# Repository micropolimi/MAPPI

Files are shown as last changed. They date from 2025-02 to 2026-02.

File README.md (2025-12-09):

# MAPPI - Macroscopic Plant Projection Imaging

License

🚀 **Open Software & Hardware for Plant Imaging**

---

## 🌱 Overview
MAPPI (MAcroscopic Plant Projection Imaging) is an open-source project dedicated to advanced imaging of growing plants. It provides tools for:
✅ Software-controlled optical imaging using cameras and LEDs.
✅ Automated data analysis with region-of-interest (ROI) registration.
✅ Hardware integration for multiview plant growth monitoring.

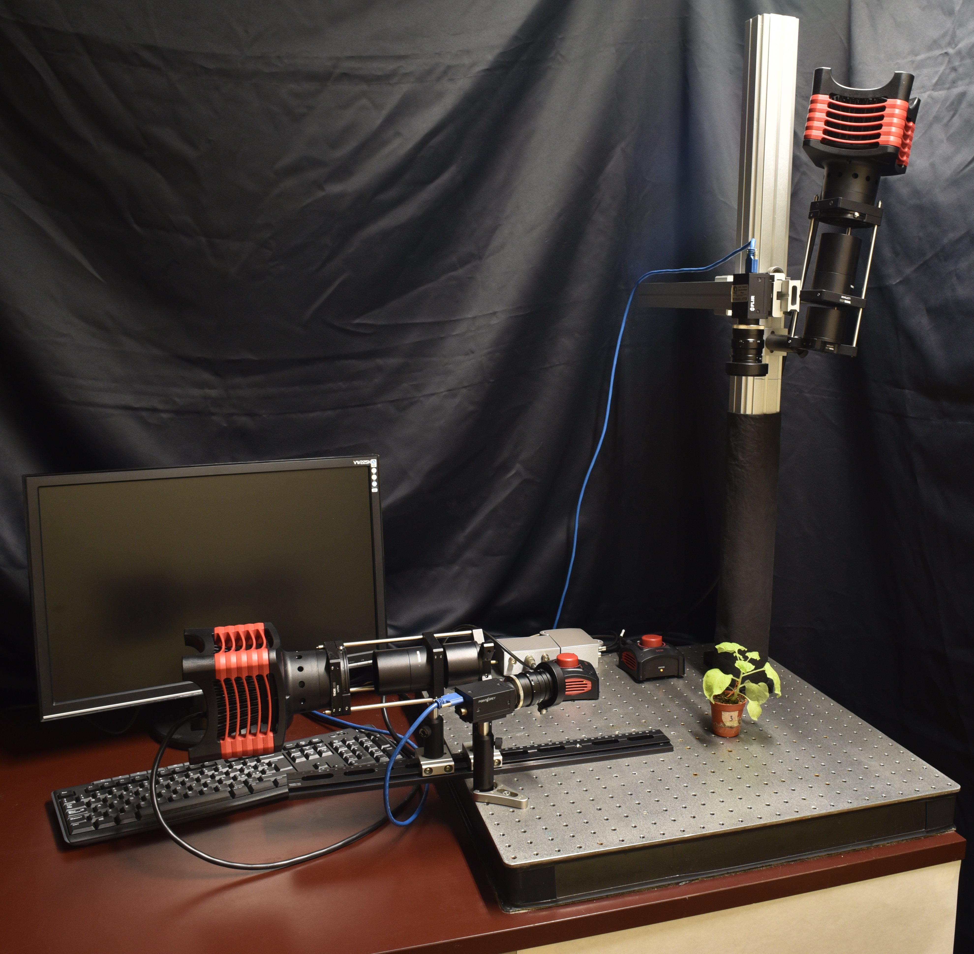
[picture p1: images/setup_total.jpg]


---

## 🖥️ Software Installation
The control software for MAPPI is based on [Scope Foundry]. To set up the python environment and install the software:
1. Follow the [Scope Foundry installation] guidelines.
2. Download or clone the [MAPPI code], which runs cameras, LEDs, and controls triggers with a dedicated [App].

---

## ⚙️ Software Usage
By running the *plant_app* script, a new window appears on the screen, allowing control of the MAPPI system. All acquisition parameters can be configured through the *PlantTimeLapseDualMeasure* widget, located above the canvas. A detailed description of the options offered by the *PlantTimeLapseDualMeasure* is provided below.

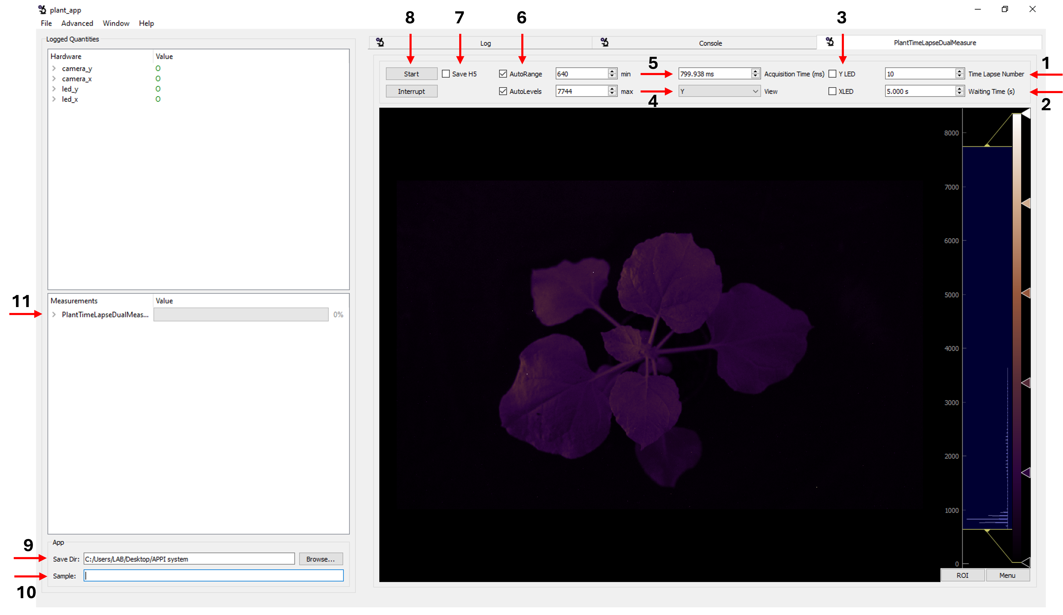
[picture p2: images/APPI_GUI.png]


1) **Time Lapse Number**: Number of time points to be acquired.
2) **Waiting Time**: Time interval between consecutive time points.
3) **X - Y LED**: When not measuring, ticking the checkbox toggles the selected LED on or off. Facilitates accurate positioning of the sample prior to measurement. 
4) **View**: Enables switching from one view to another.
5) **Acquisition Time**: Exposure time. Use 4) to select the appropriate channel and set the exposure time. Exposure time may differ between channels X and Y.
6) **AutoRange** and **AutoLevels**: When unchecked, these boxes allow the user to manually define the displayed portion of the Field of View and and set the grayscale level limits.
7) **Save H5**: When this checkbox is checked, pressing the Start button will save a new acquisition. 
8) **Start** and **Interrupt**: These two buttons start and stop the measurment respectively.
9) **Save Dr**: Directory where data will be saved.
10) **Sample**: Name of the file to be saved.
11) **State bar**: Displays the percentage of completed acquisitions.

---

## 📊 Data Analysis
For analyzing MAPPI datasets of growing plants, we recommend using the [napari ROI Registration plugin]. This plugin is specifically designed for time-lapse registration of regions-of-interest.

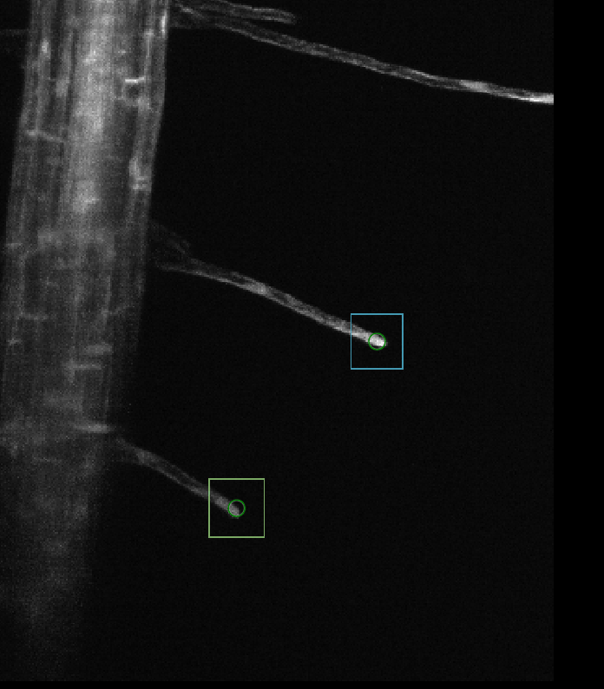
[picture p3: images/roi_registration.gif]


🔹 _Provides precise region tracking over time._   
🔹 _Easy-to-use with napari interface._

---

## 🛠️ Hardware Components
A list of all the components necessary to reproduce the MAPPI platform is available at the following [link].

---

## 🏗️ Hardware Installation
The MAPPI setup can be efficiently replicated by following the detailed step-by-step guide available [here].

---

## 🔬 3D-printed imaging chambers
Use MAPPI in combination with custom-made 3D-printed rhizoboxes to perform root imaging under near-physiological conditions. 

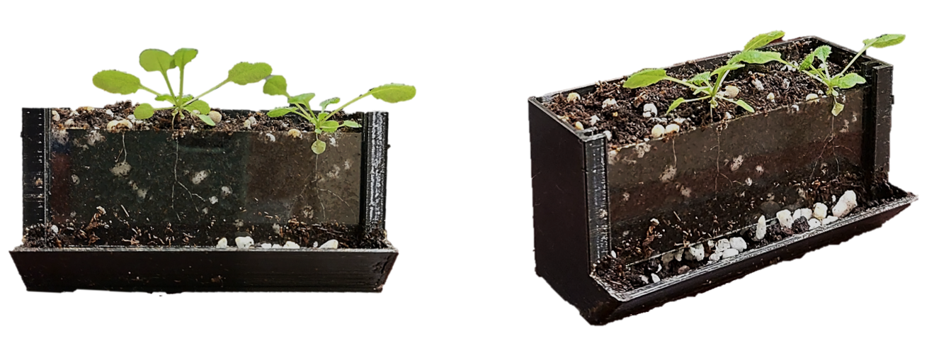
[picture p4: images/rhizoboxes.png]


We provide detailed [instructions] to reproduce the rhizoboxes and all the equipment needed to perform reliable shoot-to-root and root-to-shoot experiments on macroscopic plants. All the necessary STL files for 3D printing the equipment are available in the following [folder].

---

## 🍃 Case study
🚧 _Work in progress._ Stay tuned for updates!

---

## 🔓 License

Distributed under the terms of the [BSD-3] license,
the MAPPI code is free and open source software

---

## 📬 Contribute & Support
Have suggestions or issues? Feel free to [file an issue] or contribute to the project!

🔗 **Useful Links:**
- [Scope Foundry] - Imaging framework
- [Scope Foundry Installation] - Step-by-step setup guide
- [MAPPI Code] - Source files
- [napari ROI Registration Plugin] - Data analysis tool

[Scope Foundry]: https://scopefoundry.org/
[Scope Foundry installation]: https://scopefoundry.org/docs/1_getting-started/
[file an issue]: https://github.com/micropolimi/APPI/issues
[MAPPI code]: https://github.com/micropolimi/APPI/raw/main/src
[App]: https://github.com/micropolimi/APPI/raw/main/src/plant_app.py
[napari Roi Registration plugin]: https://www.napari-hub.org/plugins/napari-roi-registration
[BSD-3]: http://opensource.org/licenses/BSD-3-Clause
[here]: https://github.com/micropolimi/APPI/blob/main/docs/hardware.md
[link]: https://github.com/micropolimi/APPI/blob/main/docs/components.md
[folder]: https://github.com/micropolimi/APPI/tree/main/docs/STL_files
[instructions]: https://github.com/micropolimi/APPI/blob/main/docs/3D_printing.md

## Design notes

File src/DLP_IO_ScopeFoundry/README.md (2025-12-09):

# DLP_IO_ScopeFoundry
ScopeFoundry code for IO board DLP-IO8-G USB-BASED 8-CHANNEL DATA ACQUISITION MODULE

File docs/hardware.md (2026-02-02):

# Build your own MAPPI platform

This section presents a step-by-step guide to facilitate the replication of the MAPPI setup, using the components listed at the following [link].

## Horizontal arm



### Step 1: LED, lens and filter units.
#### LED unit
Begin by taking the LED (1) and mounting the [SM2L05] component onto it (2). Next, place the [LCP36] on top of the [SM2L05] and insert and fix three rods ([ER8-P4], 3). Position the rods to minimize the portion which extends beyond the cage on the LED side. Using three rods instead of four will facilitate the installation of the subsequent components. Finally, mount the iris ([LCP50D]) in such a way that it remains easily accessible once the entire setup is assembled (4).



#### Lens unit
Take the clamping platform ([XT66C4], 1) and mount the [post holder] on top of it (2). Then add the [post] (3), and finally mount the cage that will hold the lens ([LCP34/M], 4).



#### Filter unit
Take the clamping platform ([XT66C4], 1) and mount the [post holder] on top of it (2). Add the [post] (3), and then mount the cage that will be used to hold the short-pass filter ([LCP33/M], 4). Screw a [retaining ring] into the cage and insert the filter into the cage (5). A second retaining ring is not required to secure the filter, as the [SM1A2] adapter will serve this function during the assembly of the entire horizontal arm.



### Step 2: assemble the horizontal arm
Mount the horizontal rail ([XT66SD-500], 1) onto the breadboard. Pay close attention to positioning, ensuring that there is sufficient space on the breadboard to place the sample 45 cm away from the last lens once the entire setup is assembled. Fix the lens unit onto the rail (2). At this stage, the exact position of the lens unit along the rail is not critical. Once the entire illumination unit is complete, it can be precisely positioned along the rail thanks to the movable clamping platforms. Next, add the LED unit (3), followed by the filter unit (4). The LED, lens, and filter units are connected using rods. You can now screw the lens ([AC508-075-A-ML]) onto the lens unit (5). The distance between the iris mounted on the LED unit and the center of the lens must be approximetely 9 cm. As a result, the lens will create an enlarged image of the homogeneous illumination plane formed at the iris, located 45 cm away. The most effective way to adjust the distance between the iris and the lens is to temporarily remove the filter unit from the rail and observe how the illumination plane behaves at a distance of 45 cm from the lens, while adjusting the position of the LED unit relative to the lens unit. The optimal position is the one that maximizes the homogeneity of the illumination at 45 cm. Open and close the iris aperture to ensure that the homogeneity of the illumination plane does not depend on the iris aperture. Mount the [SM2L15] tube onto lens (6).



Once you are satisfied with the positioning of the LED relative to the lens, you can reattach the filter unit to the rail. The filter unit should be positioned at the focal plane of the lens, where the image of the LED source (four emitters) is formed (see image below). Identify this point along the optical path and fix the filter unit in place.

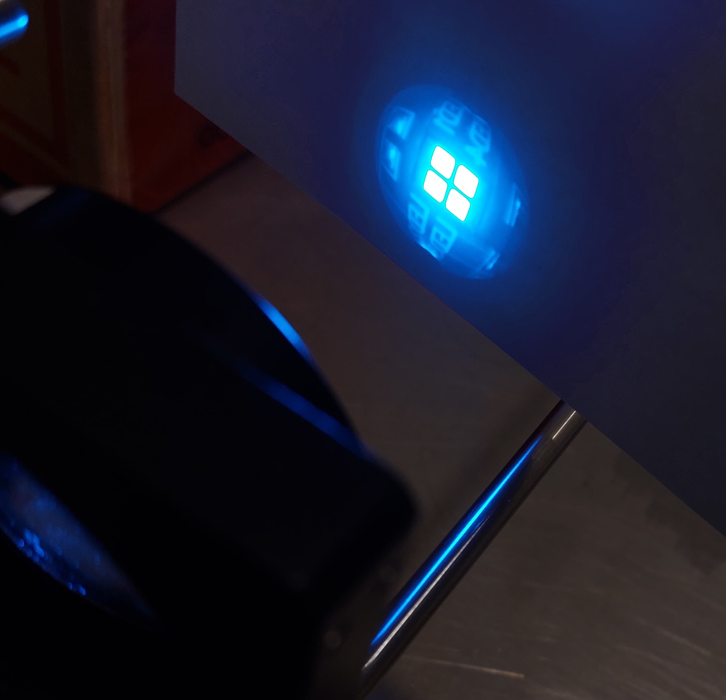
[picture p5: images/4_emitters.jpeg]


Add the [SM1A2] to the filter unit (7). This will secure the filter within its cage. Mount the [SM2L20] tube onto the SM1A2 (8). The illumination unit is now complete. You can adjust its position on the rail and place it in its final location.



Mount the post holder onto the base adapter ([BE1]), and secure them to the breadboard using a [clamping fork] (9). Insert the [post] (10) and screw the camera onto it (11). You can now connect the camera. Mount the objective onto the camera (12), add the 3D-printed support for the filter (13), and then screw in the [SM2L05] tube containing the mounted band-pass filter (14). The horizontal arm of the MAPPI setup is now complete. 



## Vertical arm



### Step 1: camera and illumination units
#### Camera unit
For the vertical arm, the camera must be mounted on a clamping platform ([XT66C4]). Even when using the shortest screw, it is not possible to secure the camera directly to the platform because the threaded hole on the camera is too shallow. To resolve this, two metal rings (available [here]) should be used to increase the effective thickness, as shown in panel 1. Align the rings with the hole on the camera (2), then attach the camera to the clamping platform (3). You're camera unit is ready. Any other strategy to increase the thickness and fix the camera to the platform can be used. 

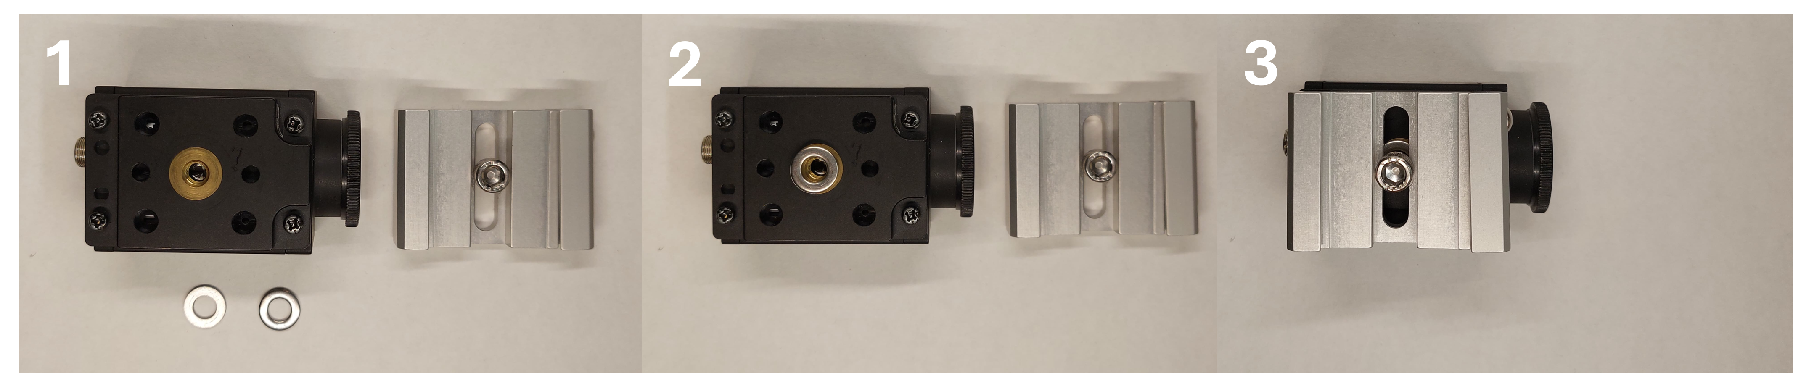
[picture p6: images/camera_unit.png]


#### Illumination unit
The same instructions used to build the horizontal illumination unit should be followed to assemble the vertical one. The only difference lies in how the lens unit is mounted onto the clamping platform. In this case, the lens unit is secured to the clamping platform using a clamping fork (see figure below). This configuration allows the vertical illumination unit to be slightly tilted rather than perfectly vertical. In this way, it is possible to illuminate the same area imaged by the camera while keeping the camera parallel to the sample plane.

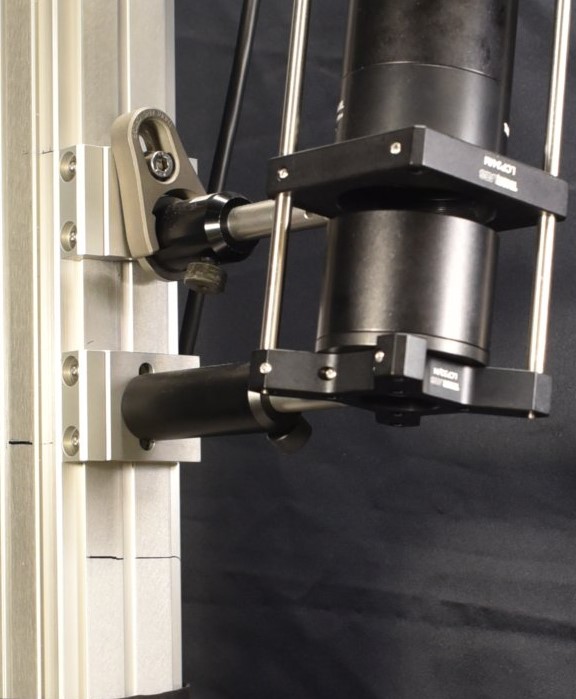
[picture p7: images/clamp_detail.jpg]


### Step 2: assemble the vertical arm
Mount the vertical shaft ([XT66-100]) using the vertical mounting plate ([XT66P1]), and cover the lower part of the shaft with a black cloth to avoid unwanted light reflections during measurements (1). Mount the illumination unit on one side of the shaft using the clamping platforms (2). Adjust the height of the illumination unit along the shaft according to the sample dimensions, maintaining a distance of 45 cm between the last lens and the sample.
Mount one of the two double dovetail clamps ([XT66C2]) on another side of the shaft (3), specifically on the side where the horizontal arm of the MAPPI platform is located. Attach the cross bracket ([XT66CB]) to the double dovetail clamp (4), then mount the second XT66C2 onto the cross bracket (5). Add the rail ([XT66DP-500]) that will hold the camera vertically above the sample (6). Mount the camera unit onto this rail near the LED (7). Finally, screw the objective (already fitted with the filter) onto the camera, and connect the camera (8). Your MAPPI platform is now complete.



[link]: https://github.com/micropolimi/MAPPI/blob/main/docs/components.md
[LCP36]: https://www.thorlabs.de/thorproduct.cfm?partnumber=LCP36
[ER8-P4]: https://www.thorlabs.com/thorproduct.cfm?partnumber=ER8-P4
[LCP50D]: https://www.thorlabs.com/thorproduct.cfm?partnumber=LCP50D
[XT66C4]: https://www.thorlabs.com/thorproduct.cfm?partnumber=XT66C4
[LCP34/M]: https://www.thorlabs.com/thorproduct.cfm?partnumber=LCP34/M
[LCP33/M]: https://www.thorlabs.com/thorproduct.cfm?partnumber=LCP33/M
[SM1A2]: https://www.thorlabs.com/thorproduct.cfm?partnumber=SM1A2
[XT66SD-500]: https://www.thorlabs.com/thorproduct.cfm?partnumber=XT66SD-500
[AC508-075-A-ML]: https://www.thorlabs.com/thorproduct.cfm?partnumber=AC508-075-A-ML
[SM2L15]: https://www.thorlabs.com/thorproduct.cfm?partnumber=SM2L15
[SM1A2]: https://www.thorlabs.com/thorproduct.cfm?partnumber=SM1A2
[SM2L20]: https://www.thorlabs.com/thorproduct.cfm?partnumber=SM2L20
[BE1]: https://www.thorlabs.com/thorproduct.cfm?partnumber=BE1/M#ad-image-0
[SM2L05]: https://www.thorlabs.com/thorproduct.cfm?partnumber=SM2L05
[XT66-100]: https://www.thorlabs.com/thorproduct.cfm?partnumber=XT66-100
[XT66P1]: https://www.thorlabs.com/thorproduct.cfm?partnumber=XT66P1
[XT66C2]: https://www.thorlabs.com/thorproduct.cfm?partnumber=XT66C2
[XT66CB]: https://www.thorlabs.com/thorproduct.cfm?partnumber=XT66CB
[XT66DP-500]: https://www.thorlabs.com/thorproduct.cfm?partnumber=XT66DP-500
[post]: https://www.thorlabs.com/thorproduct.cfm?partnumber=TR75/M
[post holder]: https://www.thorlabs.com/thorproduct.cfm?partnumber=PH75/M-P5#ad-image-0
[retaining ring]:https://www.thorlabs.com/thorproduct.cfm?partnumber=SM1RR
[clamping Fork]:https://www.thorlabs.com/thorproduct.cfm?partnumber=CF125C/M#ad-image-0
[here]:https://www.thorlabs.com/thorproduct.cfm?partnumber=HW-KIT2/M

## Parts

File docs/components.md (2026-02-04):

# List of components

| Component | Image | Provider | Description | Quantity | Unit | Price of a single item |
|---|---|---|---|---|---|---|
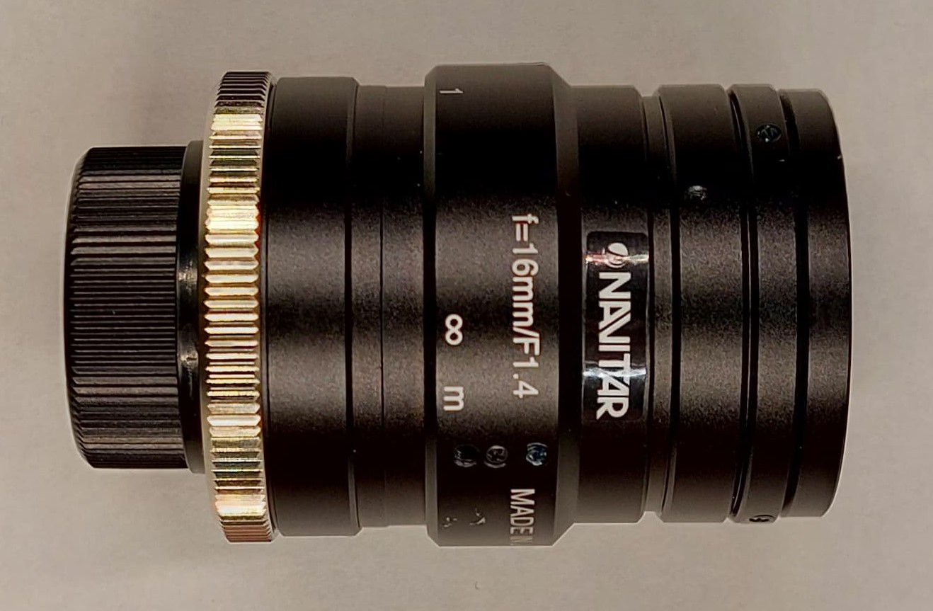
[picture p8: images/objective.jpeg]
|[MVL16M1]||Thorlabs|16 mm EFL, f/1.4, for 1" C-Mount Format Cameras, with Lock|2|Detection Unit|526,87 €|
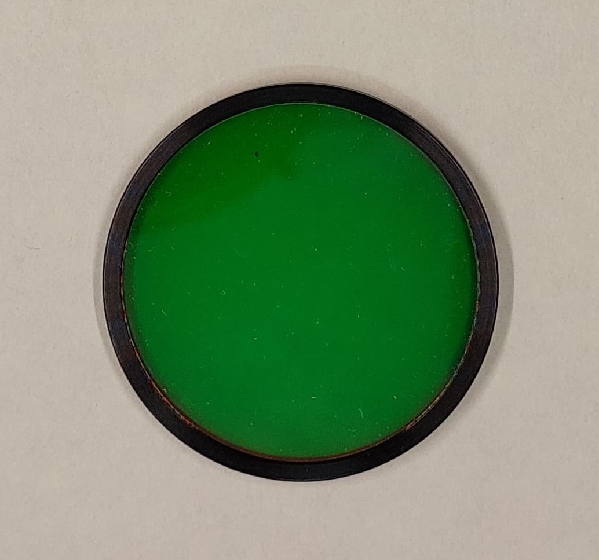
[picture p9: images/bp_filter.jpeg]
|[B-P Filter]||Edmund Optics|543nm CWL, 50mm Dia, 22nm Bandwidth, OD 6 Fluorescence Filter|2|Detection Unit|912,58 €|
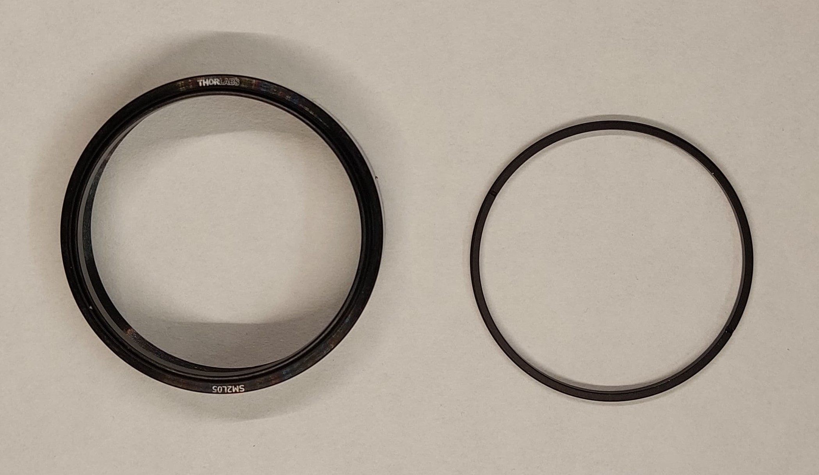
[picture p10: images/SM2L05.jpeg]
|[SM2L05]||Thorlabs|SM2L05 - SM2 Lens Tube, 0.5" Thread Depth, One Retaining Ring Included|4|Detection Unit/LED unit|27,64 €|
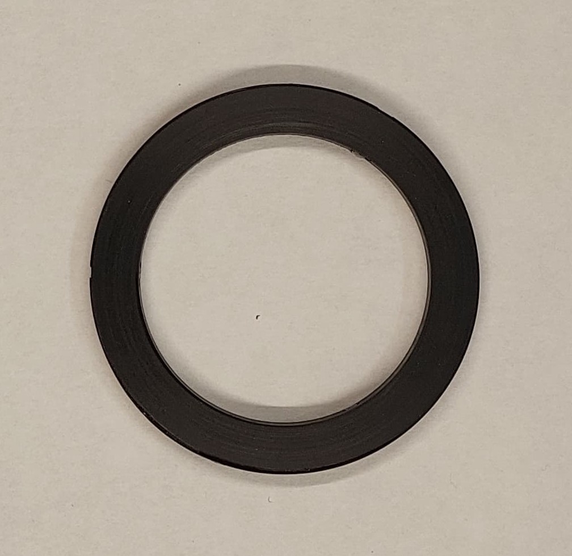
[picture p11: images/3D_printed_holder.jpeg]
|3D-printed filter holder||Custom made|3D-printed adapter for direct filter mounting on the objective|2|Detection Unit| - |
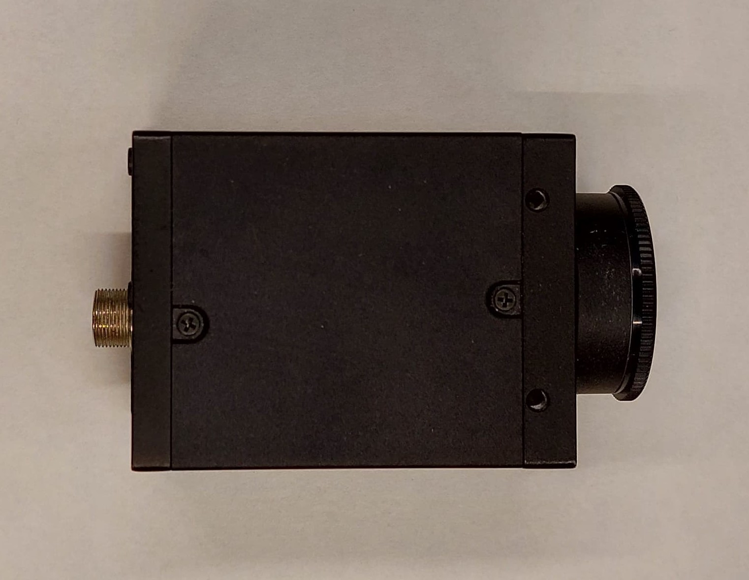
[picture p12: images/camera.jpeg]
|[camera]||Edmund optics|GS3-U3-23S6M-C 1/1.2" FLIR Grasshopper®3 High Performance USB 3.0 Monochrome Camera|2|Detection Unit|1.180 €|
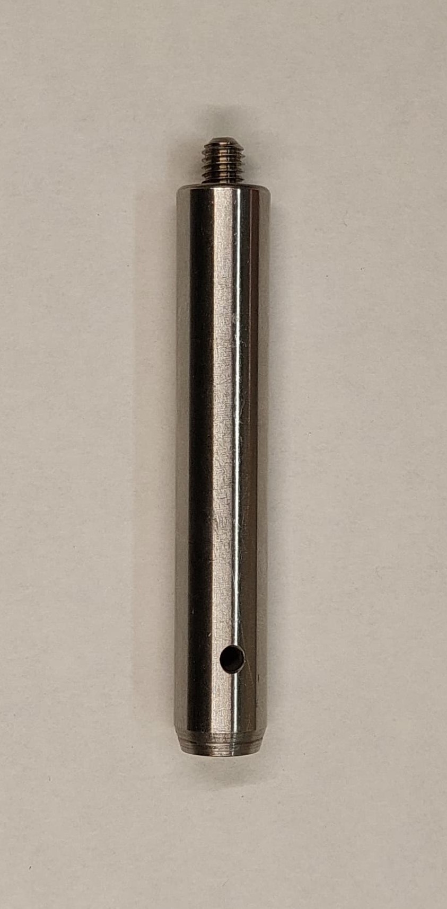
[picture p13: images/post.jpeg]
|[Post]||Thorlabs|TR75/M-P5 - Ø12.7 mm Optical Post, SS, M4 Setscrew, M6 Tap, L = 75 mm, 5 Pack|1|H/V arm|26,94 €|
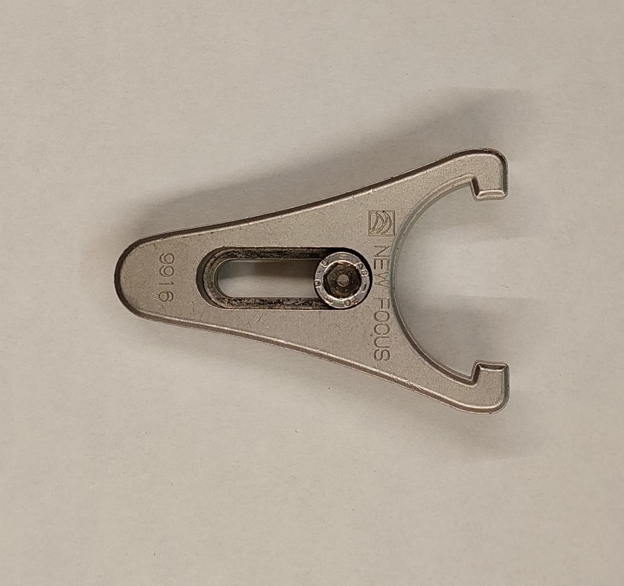
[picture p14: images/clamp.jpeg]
|[Clamping Fork]||Thorlabs|CF125C/M - Clamping Fork for Ø1.25" Pedestal Bases, 31.5 mm Counterbored Slot, M6 x 1.0 Captive Screw|2|H detection unit/V lens unit|12,48 €|
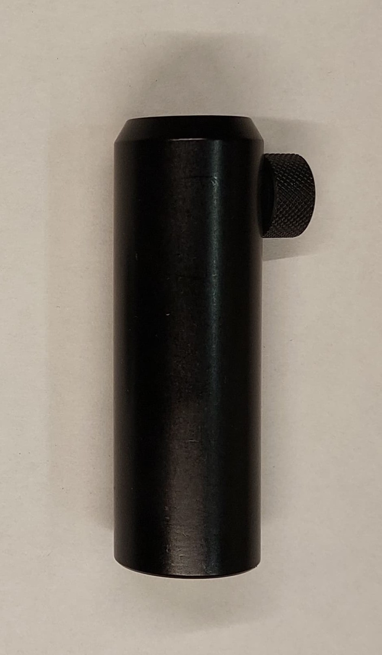
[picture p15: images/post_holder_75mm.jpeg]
|[Post Holder (75 mm)]||Thorlabs|PH75/M-P5 - Ø12.7 mm Post Holder, Spring-Loaded Hex-Locking Thumbscrew, L=75 mm, 5 Pack|1|H/V arm|44,58 €|
|[Base Adapter]||Thorlabs|BE1/M - Ø31.8 mm Studded Pedestal Base Adapter, M6 Threads|2|H detection unit/V lens unit|10,54 €|
|[SM2L15]||Thorlabs|SM2L15 - SM2 Lens Tube, 1.5" Thread Depth, One Retaining Ring Included|2|H/V arm|33,11 €|
|[SM2L20]||Thorlabs|SM2L20 - SM2 Lens Tube, 2" Thread Depth, One Retaining Ring Included|2|H/V arm|33,66 €|
|[SM1A2]||Thorlabs|SM1A2 - Adapter with External SM1 Threads and Internal SM2 Threads|2|H/V arm|27,62 €|
|[AC508-075-A-ML]||Thorlabs|f=75 mm, Ø2" Achromatic Doublet, SM2-Threaded Mount, ARC: 400-700 nm|2|H/V arm|176,77 €|
|[LCP33/M]||Thorlabs|30 mm to 60 mm Cage Plate Adapter, M4 Tap|2|Filter Unit|45,06 €|
|[FESH0500]||Thorlabs|Ø25.0 mm Shortpass Filter, Cut-Off Wavelength: 500 nm|2|Filter Unit|153,86 €|
|[XT66C4]||Thorlabs|Clamping Platform for 66 mm Rails, 1/4" Counterbored Slot, 40 mm Long|5|H/V arm|32,35 €|
|[LCP34/M]||Thorlabs|LCP34/M - 60 mm Cage Plate, SM2 Threads, 0.5" Thick, M4 Tap (Two SM2RR Retaining Rings Included)|2|Lens Unit|43,91 €|
|[LCP50D]||Thorlabs|60 mm Cage System Iris Diaphragm (Ø2.0 - Ø50.0 mm)|2|LED Unit|219,53 €|
|[SOLIS-470C]||Thorlabs|High-Power LED for Microscopy, 470 nm (Blue), 3.0 W (Min)|2|LED Unit|1.424,19 €|
|[DC20]||Thorlabs|High-Power Driver for Solis® LEDs, 10 A Max, 14.0 V Max|2|LED Unit|560,71 €|
|[ER8-P4]||Thorlabs|Cage Assembly Rod, 8" Long, Ø6 mm, 4 Pack|2|LED Unit|46,77 €|
|[LCP36]||Thorlabs|60 mm Cage Plate with Ø2.2" (Ø56.0 mm) Double Bore for SM2 Lens Tube Mounting|2|LED Unit|48,80 €|
|[XT66SD-500]||Thorlabs|66 mm Single Dovetail Rail with Mounting Counterbores, L = 500 mm|1|H arm|92,87 €|
|[XT66-1000]||Thorlabs|66 mm Construction Rail, L = 100 mm|1|V arm|171,42 €|
[XT66P1]||Thorlabs|Vertical Mounting Plate for 34 mm & 66 mm Optical Rails|1|V arm|41,02 €|
|[XT66C2]||Thorlabs|40 mm Long Double Dovetail Clamp for 66 mm Rails |2|V arm|24,91 €|
|[XT66DP-500]||Thorlabs|66 mm Double Dovetail Rail, L = 500 mm|1|V arm|52,00 €|
|[XT66CB]||Thorlabs|Cross Bracket for 66 mm Rails|1|V arm|24,03 €|
|[DLP-IO8-G]||Digikey|MODULE DATA-ACQUISITION 8-CH|2|H/V arm|26,23 €|
|[Breadboard]||Thorlabs|B6060L - Nexus Breadboard, 600 mm x 600 mm x 60 mm, Sealed M6 x 1.0 Mounting Holes|1|-|1116,05 €|
|[Table clamp]||Thorlabs|CL5 - Table Clamp, L-Shap|2|V arm|5,15 €|
|Double BNC cable||-|Double BNC cable|2|H/V arm|-|
|[Retaining ring]||Thorlabs|SM1RR - SM1 Retaining Ring for Ø1" Lens Tubes and Mounts |2|Filter unit|4,74 €|
|[Screw kit]||Thorlabs|HW-KIT2/M - M6 Cap Screw and Hardware Kit|1|-|135,76 €|

[MVL16M1]: https://www.thorlabs.com/thorproduct.cfm?partnumber=MVL16M1
[camera]: https://www.edmundoptics.com/p/gs3-u3-23s6m-c-112-grasshopper-usb-30-monochrome-camera/30859/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
[SM2L05]: https://www.thorlabs.com/thorproduct.cfm?partnumber=SM2L05
[Base Adapter]: https://www.thorlabs.com/thorproduct.cfm?partnumber=BE1/M#ad-image-0
[SM2L15]: https://www.thorlabs.com/thorproduct.cfm?partnumber=SM2L15
[SM2L20]: https://www.thorlabs.com/thorproduct.cfm?partnumber=SM2L20
[SM1A2]: https://www.thorlabs.com/thorproduct.cfm?partnumber=SM1A2
[AC508-075-A-ML]: https://www.thorlabs.com/thorproduct.cfm?partnumber=AC508-075-A-ML
[LCP33/M]: https://www.thorlabs.com/thorproduct.cfm?partnumber=LCP33/M
[FESH0500]: https://www.thorlabs.com/thorproduct.cfm?partnumber=FESH0500
[XT66C4]: https://www.thorlabs.com/thorproduct.cfm?partnumber=XT66C4
[LCP34/M]: https://www.thorlabs.com/thorproduct.cfm?partnumber=LCP34/M
[LCP50D]: https://www.thorlabs.com/thorproduct.cfm?partnumber=LCP50D
[SOLIS-470C]: https://www.thorlabs.com/thorproduct.cfm?partnumber=SOLIS-470C
[DC20]: https://www.thorlabs.com/thorproduct.cfm?partnumber=DC20
[ER8-P4]: https://www.thorlabs.com/thorproduct.cfm?partnumber=ER8-P4
[LCP36]: https://www.thorlabs.de/thorproduct.cfm?partnumber=LCP36
[XT66SD-500]: https://www.thorlabs.com/thorproduct.cfm?partnumber=XT66SD-500
[XT66P1]: https://www.thorlabs.com/thorproduct.cfm?partnumber=XT66P1
[XT66-1000]: https://www.thorlabs.com/item/XT66-1000
[XT66C2]: https://www.thorlabs.com/thorproduct.cfm?partnumber=XT66C2
[XT66DP-500]: https://www.thorlabs.com/thorproduct.cfm?partnumber=XT66DP-500
[XT66CB]: https://www.thorlabs.com/thorproduct.cfm?partnumber=XT66CB
[DLP-IO8-G]: https://www.digikey.it/it/products/detail/dlp-design-inc/DLP-IO8-G/1894342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
[Post Holder (75 mm)]: https://www.thorlabs.com/thorproduct.cfm?partnumber=PH75/M-P5#ad-image-0
[Post]: https://www.thorlabs.com/thorproduct.cfm?partnumber=TR75/M-P5
[B-P Filter]:https://www.edmundoptics.eu/p/543nm-cwl-50mm-dia-22nm-bandwidth-od-6-fluorescence-filter/21586/
[Clamping Fork]:https://www.thorlabs.com/thorproduct.cfm?partnumber=CF125C/M#ad-image-0
[Breadboard]:https://www.thorlabs.com/thorproduct.cfm?partnumber=B6060L
[Table clamp]:https://www.thorlabs.com/thorproduct.cfm?partnumber=CL5
[Retaining ring]:https://www.thorlabs.com/thorproduct.cfm?partnumber=SM1RR
[Screw kit]:https://www.thorlabs.com/thorproduct.cfm?partnumber=HW-KIT2/M

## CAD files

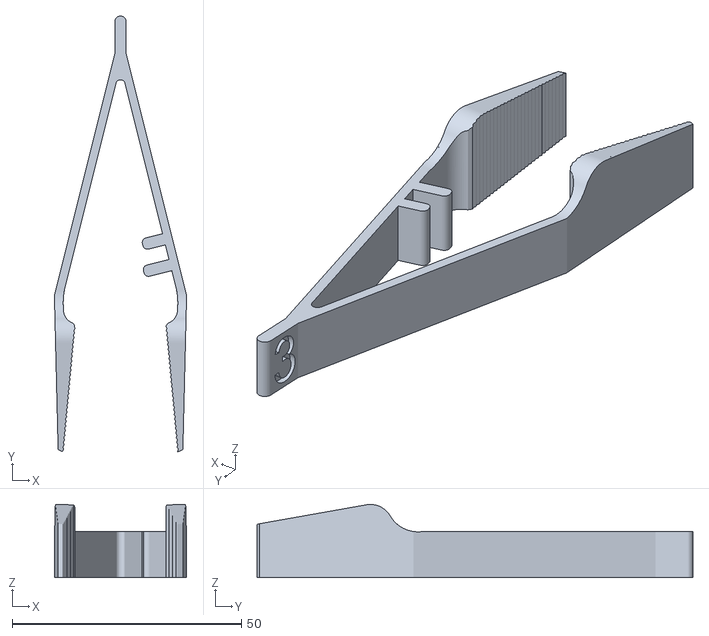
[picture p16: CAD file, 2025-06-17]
docs/STL_files/Wounding_tweezer_#3.stl
28.9 x 95.1 x 16.0

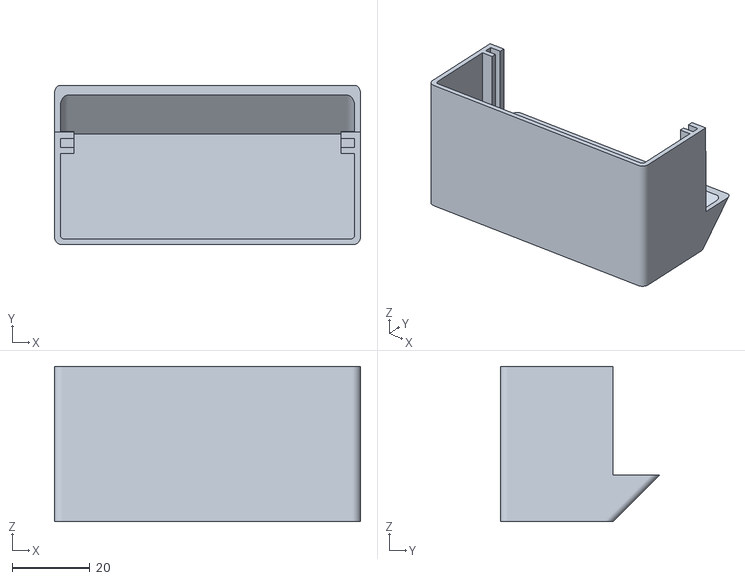
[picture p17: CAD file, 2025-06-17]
docs/STL_files/Arabidopsis_rhyzobox.stl
78.8 x 41.1 x 40.0

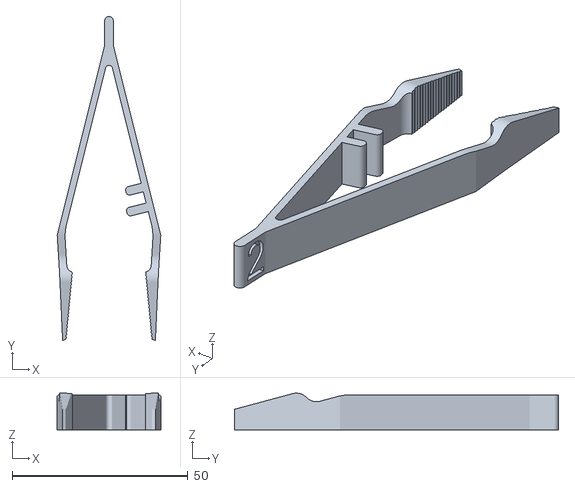
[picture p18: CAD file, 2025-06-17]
docs/STL_files/Wounding_tweezer_#2.stl
29.5 x 92.3 x 10.5

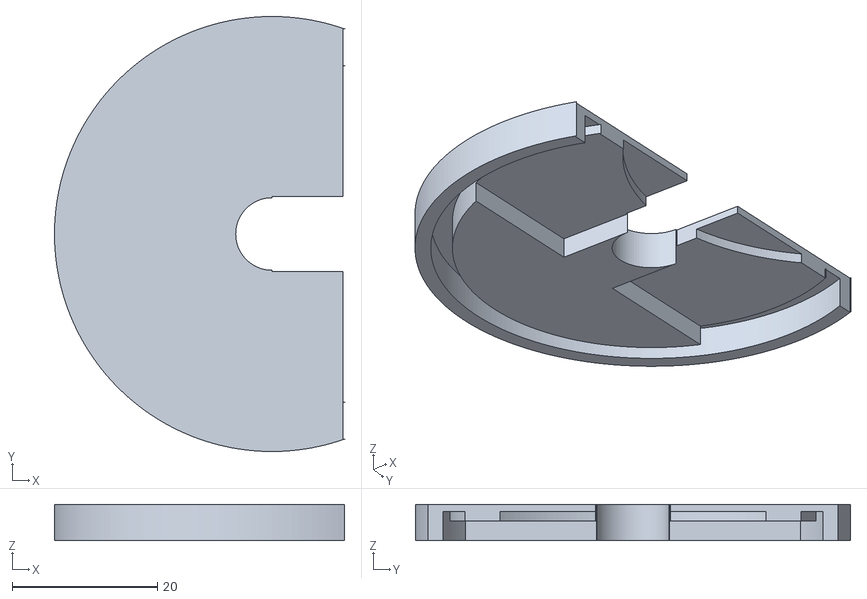
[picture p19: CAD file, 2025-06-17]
docs/STL_files/Soil_cover_top.stl
40.0 x 60.0 x 5.00

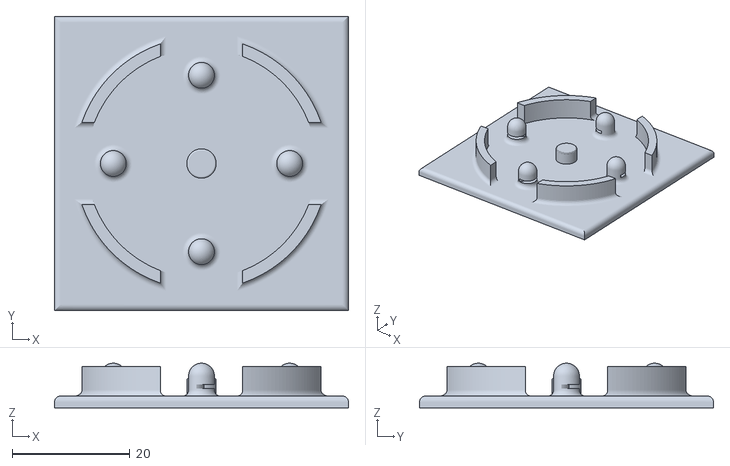
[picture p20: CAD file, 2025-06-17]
docs/STL_files/Submersion_pot-holder.stl
50.0 x 50.0 x 7.60

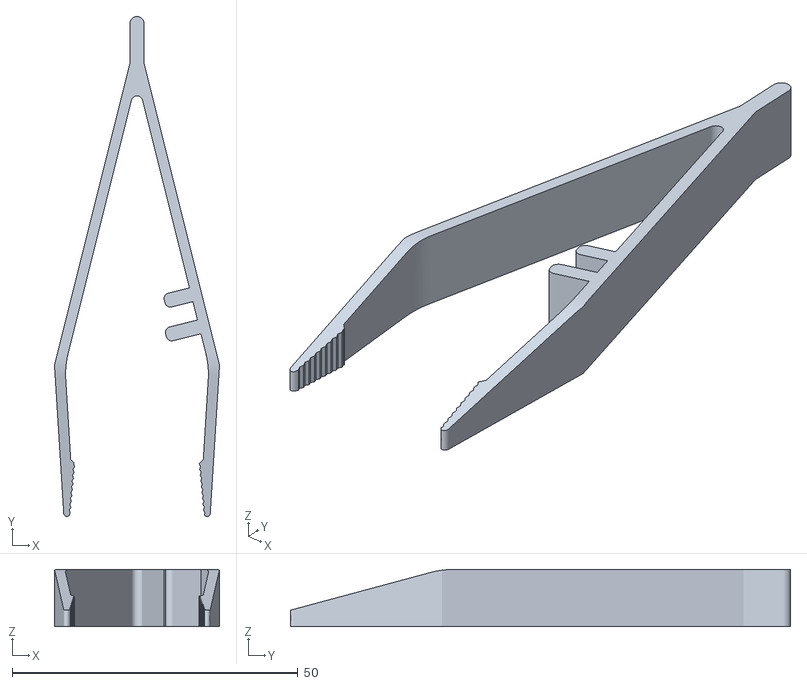
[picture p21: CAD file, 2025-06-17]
docs/STL_files/Wounding_tweezer_#1.stl
28.9 x 87.6 x 10.0

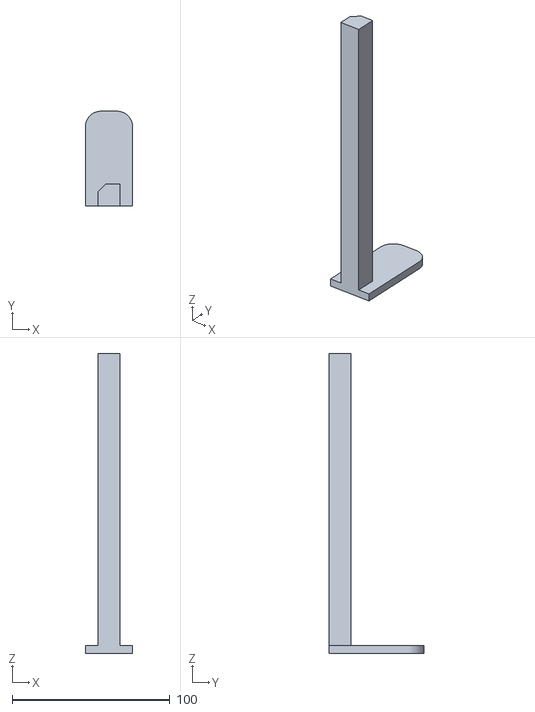
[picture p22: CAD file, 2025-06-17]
docs/STL_files/Light_path_barrier_support_2x.stl
30.0 x 60.0 x 190.0

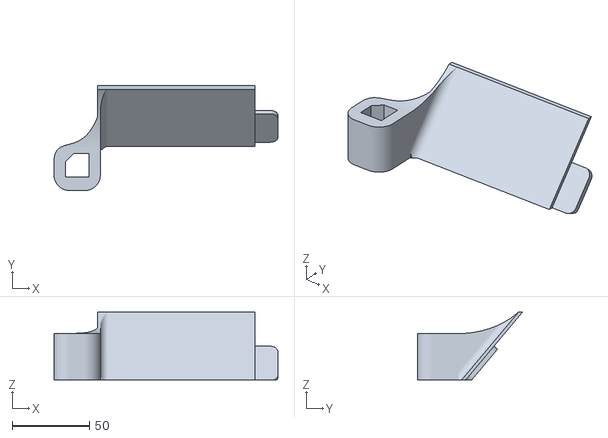
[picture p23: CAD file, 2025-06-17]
docs/STL_files/Light_path_barrier_right.stl
145.0 x 68.0 x 43.8

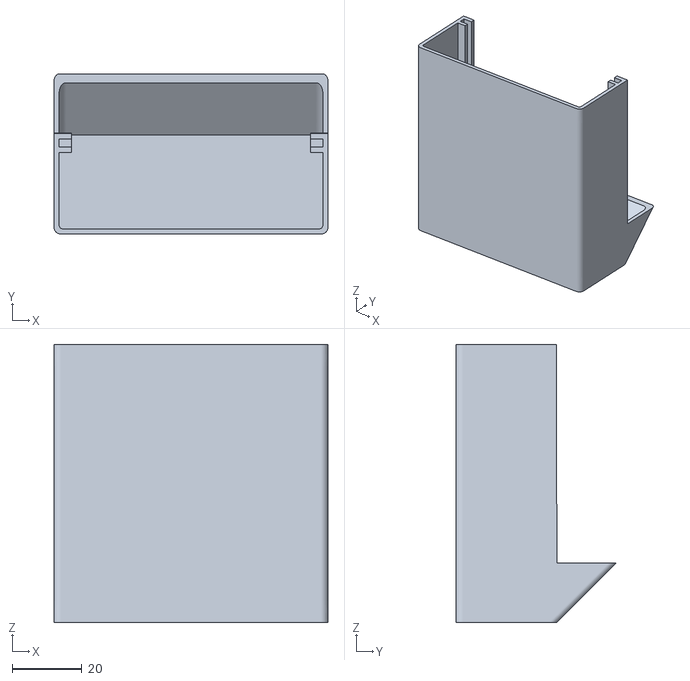
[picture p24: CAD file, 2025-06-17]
docs/STL_files/Tobacco_rhyzobox.stl
78.8 x 46.1 x 80.0

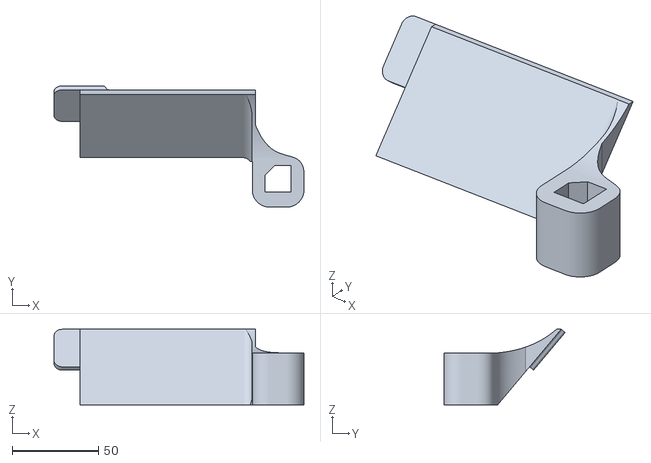
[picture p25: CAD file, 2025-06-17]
docs/STL_files/Light_path_barrier_left.stl
145.0 x 70.3 x 43.8

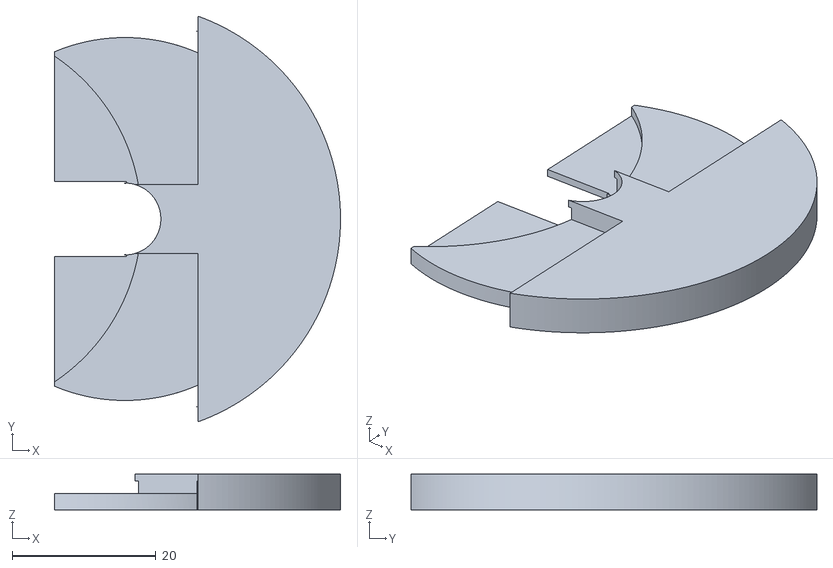
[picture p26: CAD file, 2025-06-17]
docs/STL_files/Soil_cover_bottom.stl
39.8 x 56.4 x 5.00

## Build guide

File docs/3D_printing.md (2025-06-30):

# 3D printed material

This section is dedicated to 3D-printed equipment. Printing parameters and detailed instructions are provided to easily reproduce all the items.

## Rhizoboxes

Rhyzoboxes are designed to support plant growth in a standard soil mixture while still providing direct access to and imaging of both aerial tissues and the root system. The design is self-supporting and features a 45° slope that tilts the chamber toward the front aperture, encouraging root growth toward the imaging surface. The imaging surface used is a 2 mm thick transparent acrylic sheet, cut to fit into the lateral grooves on the open side of the rhyzobox. The Arabidopsis rhyzobox is also compatible with standard non-frosted microscope glass slides (25 × 76 mm), which can be used as an imaging interface and fit into the corresponding side grooves.

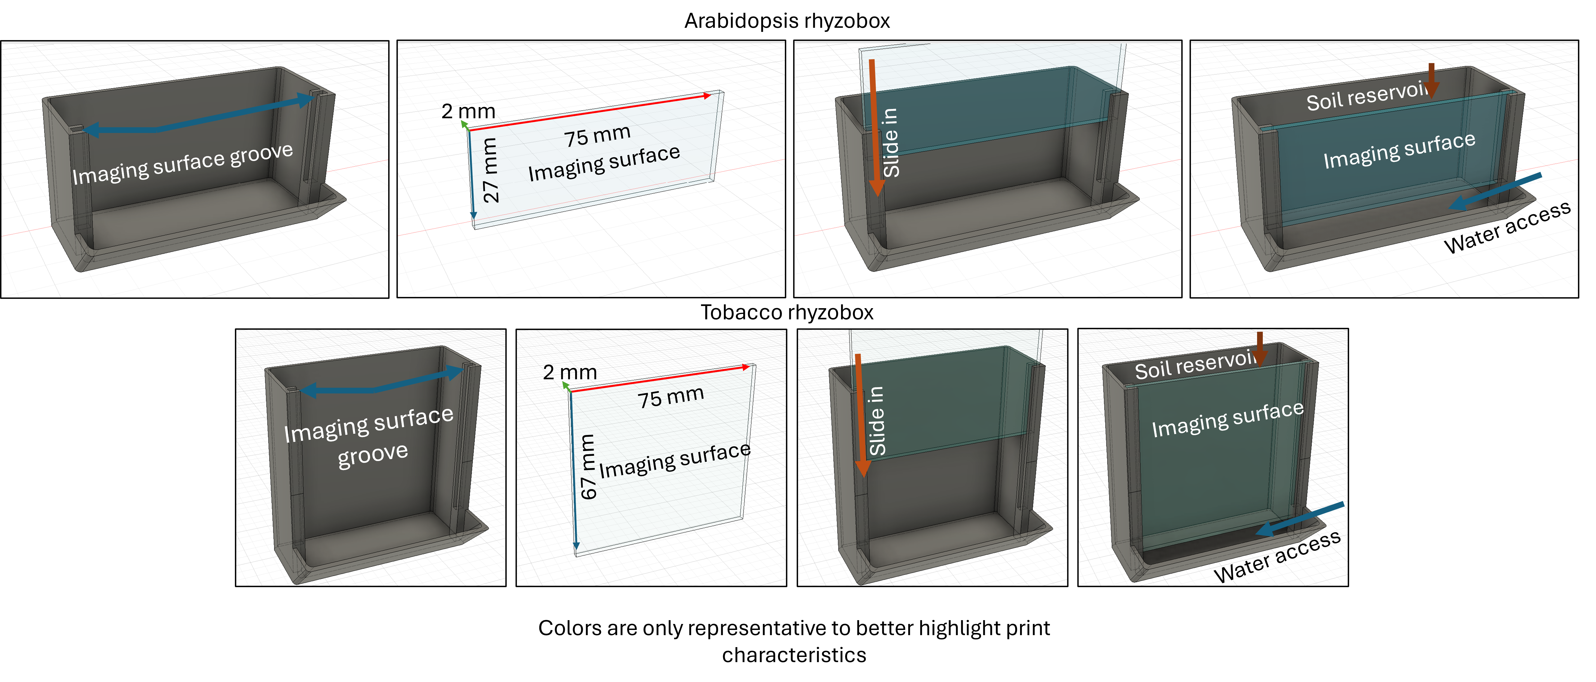
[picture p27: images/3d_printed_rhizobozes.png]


### Printing parameters
Nozzle: 0.4 mm  
Filament color: Black matte  
Filament material: PLA  
Printing temperature: 190 °C  
Build plate temperature: 60 °C (optional)  
Layer height/Resolution: 0.1-0.3 mm  
Wall thickness: 1 mm  
Top/Bottom thickness: 1 mm  
Infill density: 20%  
Infill pattern: unimportant  
Print speed: 80 mm/s  
Rafts: No  
Supports: No  

### Printing settings
PLA is used as the primary material due to its ease of printing and wide availability. However, since PLA is highly hygroscopic, it may warp over time with constant exposure to moisture. For improved durability and resistance to weathering, alternative materials such as PETG or ABS are recommended.  
It is important to use a black, preferably matte, filament, as this significantly reduces background reflections under certain lighting conditions.  
While high print resolution is not essential, going any lower than 0.3 mm may result in a rough internal surface, which can negatively affect root development.  
To ensure a sturdy and potentially reusable main frame, an infill of at least 20% is recommended.

Printer technology: Fused Deposition Modeling (FDM) is preferred, as stereolithography (SLA) resins are UV-absorbent and exhibit high fluorescence under blue-shifted excitation wavelengths.

## Submersion pot-holder setup
The submersion pot-holder is an adapter for magenta boxes to fit and lock in place pots subject to submersion to prevent sample floating. The design requires support structures for printing the locking groove, which must be removed after printing. The holder is designed to be glued to the bottom of a magenta box with water-resistant glue.



### Printing parameters
Nozzle: 0.4 mm  
Filament color: Black matte  
Filament material: PLA  
Printing temperature: 190 °C  
Build plate temperature: 60 °C (optional)  
Layer height/Resolution: 0.1-0.3 mm  
Wall thickness: 1 mm  
Top/Bottom thickness: 1 mm  
Infill density: 100%  
Infill pattern: unimportant  
Print speed: 80 mm/s  
Rafts: No  
Supports: Yes  

### Printing settings
PLA is used as the primary material due to its ease of printing and wide availability. However, since PLA is highly hygroscopic, it may warp over time with constant exposure to moisture. For improved durability and resistance to weathering, alternative materials such as PETG or ABS are recommended.  
While high print resolution is not essential, going any lower than 0.3 mm may result in a rough internal surface, which can negatively affect root development.

Printer technology: For the pot-holder, both Fused Deposition Modeling (FDM) and stereolithography (SLA) are suitable, as the printed component will not be visible within the field of view during image acquisition. 

## Soil cover print and setup
The soil cover is designed to prevent soil spillage into the submergence solution.
The design requires support structures for part of the soil cover, which must be removed after printing. 
The soil cover locks onto standard 5 cm diameter pots, securing itself around the plant’s main axis.



### Printing parameters
Nozzle: 0.4 mm  
Filament color: Black matte  
Filament material: PLA  
Printing temperature: 190 °C  
Build plate temperature: 60 °C (optional)  
Layer height/Resolution: 0.1-0.3 mm  
Wall thickness: 1 mm  
Top/Bottom thickness: 1 mm  
Infill density: 100%  
Infill pattern: unimportant  
Print speed: 80 mm/s  
Rafts: No  
Supports: Yes  

### Printing settings
PLA is used as the primary material due to its ease of printing and wide availability. However, since PLA is highly hygroscopic, it may warp over time with constant exposure to moisture. For improved durability and resistance to weathering, alternative materials such as PETG or ABS are recommended.  
While high print resolution is not essential, going any lower than 0.3 mm may result in a rough internal surface, which can negatively affect root development.

Printer technology: Since the soil cover will be visible in the field of view (FOV), Fused Deposition Modeling (FDM) is recommended. For this component, it is especially important to use a black, preferably matte, filament to minimize background reflections under certain lighting conditions.

## Wounding tweezers print and setup
The wounding tweezers are designed to apply consistent pressure across different wound surface areas. Wounding tweezer n° 1 has a wounding area of approximately 40 mm<sup>2</sup>, n° 2 around 160 mm<sup>2</sup>, and n°3 around 380 mm<sup>2</sup>.
The design does not require support structures for printing.

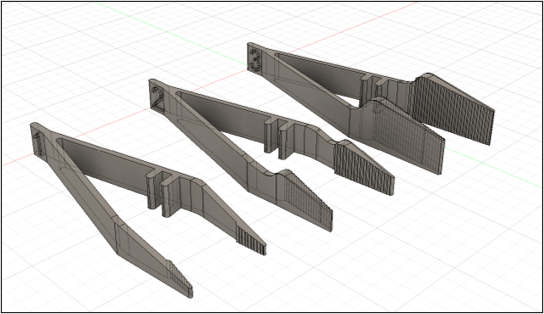
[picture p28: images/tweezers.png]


### Printing parameters
Nozzle: 0.4 mm  
Filament color: Black matte  
Filament material: PLA  
Printing temperature: 190 °C  
Build plate temperature: 60 °C (optional)  
Layer height/Resolution: 0.1-0.3 mm  
Wall thickness: 1 mm  
Top/Bottom thickness: 1 mm  
Infill density: 100%  
Infill pattern: unimportant  
Print speed: 80 mm/s  
Rafts: No  
Supports: no  

### Printing settings
PLA is used as the primary material due to its ease of printing and wide availability. However, since PLA is highly hygroscopic, it may warp over time with constant exposure to moisture. For improved durability and resistance to weathering, alternative materials such as PETG or ABS are recommended.  
While high print resolution is not essential, going any lower than 0.3 mm may result in a rough internal surface, which can negatively affect root development.

Printer technology: For the tweezers, both Fused Deposition Modeling (FDM) and stereolithography (SLA) are suitable, as the printed component will not be visible in the field of view (FOV) during image acquisition.

## Light path barrier print and setup
The light path barrier is a simple system designed to reduce crosstalk between the two orthogonal optical pathways. The design requires support structures, which must be removed after printing.

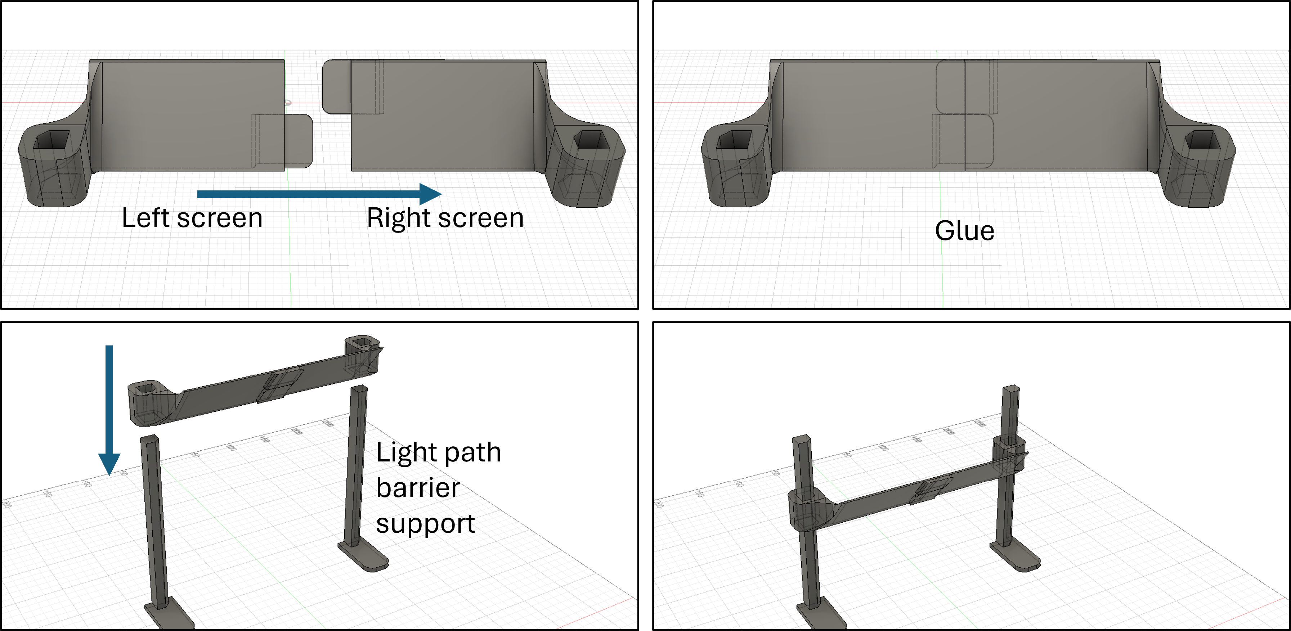
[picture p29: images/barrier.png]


### Printing parameters
Nozzle: 0.4 mm  
Filament color: Black matte  
Filament material: PLA  
Printing temperature: 190 °C  
Build plate temperature: 60 °C (optional)  
Layer height/Resolution: 0.1-0.3 mm  
Wall thickness: 1 mm  
Top/Bottom thickness: 1 mm   
Infill density: 100%  
Infill pattern: unimportant  
Print speed: 80 mm/s  
Rafts: No  
Supports: Yes  

### Printing settings
PLA is used as the primary material due to its ease of printing and wide availability. However, since PLA is highly hygroscopic, it may warp over time with constant exposure to moisture. For improved durability and resistance to weathering, alternative materials such as PETG or ABS are recommended.  
It is important to use a black, preferably matte, filament, as this significantly reduces background reflections under certain lighting conditions.  
While high print resolution is not essential, going any lower than 0.3 mm may result in a rough internal surface, which can negatively affect root development.

Printer technology: Fused Deposition Modeling (FDM) is preferred, as stereolithography (SLA) resins are UV-absorbent and exhibit high fluorescence under blue-shifted excitation wavelengths.

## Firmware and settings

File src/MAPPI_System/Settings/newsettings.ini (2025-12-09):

[app]
wheel manipulation = True
save_dir = C:/Data/251022_test_acquisizione_rapida
sample = 
data_fname_format = {timestamp:%y%m%d_%H%M%S}_{measurement.name}.{ext}
propose_from_file = C:\Users\giorg\AppData\Local\Programs\Microsoft VS Code
dark_mode = 0

[hw/camera_y]
connected = True
debug_mode = True
name = Point Grey Research 17289280 Grasshopper3 GS3-U3-23S6M
number = 0
serial = 17289280
image_width = 1920
image_height = 1200
frame_rate = 1.0
exposure_time = 500.083327293396
frame_num = 10
acquisition_mode = Continuous
gain = 0.0
temperature = 33.75

[hw/camera_x]
connected = True
debug_mode = True
name = Point Grey Research 14103019 Grasshopper3 GS3-U3-23S6M
number = 0
serial = 14103019
image_width = 1920
image_height = 1200
frame_rate = 1.0
exposure_time = 500.083327293396
frame_num = 10
acquisition_mode = Continuous
gain = 0.0
temperature = 47.950000000000045

[hw/led_y]
connected = True
debug_mode = False
port = COM3
channel_1 = False

[hw/led_x]
connected = True
debug_mode = False
port = COM4
channel_1 = False

[mm/PlantTimeLapseDualMeasure]
activation = False
run_state = stop_interrupted
progress = 0.0
profile = False
camera_in_use = Y
desired_frame_rate = 1.0
time_lapse_num = 10
time_lapse_waiting_time = 2.0
frame_num = 1
LED_init_time = 0.0
xsampling = 0.058
ysampling = 0.058
zsampling = 1.0
auto_range = True
auto_levels = False
level_min = 640
level_max = 15000
save_h5 = False
refresh_period = 0.03

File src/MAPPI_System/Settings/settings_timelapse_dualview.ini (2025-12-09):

[app]
save_dir = D:/data/test_giorgia
sample = 
data_fname_format = {timestamp:%y%m%d_%H%M%S}_{measurement.name}.{ext}

[hardware/camera_y]
connected = True
debug_mode = False
name = Point Grey Research 17289280 Grasshopper3 GS3-U3-23S6M
number = 0
serial = 17289280
image_width = 1920
image_height = 1200
frame_rate = 1.0
exposure_time = 500.083327293396
frame_num = 1
acquisition_mode = Continuous
gain = 0.0
temperature = 50.25

[hardware/camera_x]
connected = True
debug_mode = False
name = Point Grey Research 14103019 Grasshopper3 GS3-U3-23S6M
number = 1
serial = 14103019
image_width = 1920
image_height = 1200
frame_rate = 1.0
exposure_time = 500.083327293396
frame_num = 1
acquisition_mode = Continuous
gain = 0.0
temperature = 50.55000000000001

[hardware/led_y]
connected = True
debug_mode = False
port = COM5
channel_1 = False

[hardware/led_x]
connected = True
debug_mode = False
port = COM3
channel_1 = False

[measurement/PlantTimeLapseDualMeasure]
activation = False
run_state = stop_interrupted
progress = 0.0
profile = False
camera_in_use = Y
acquisition_time = 500.0
time_lapse_num = 10
time_lapse_waiting_time = 5.0
frame_num = 1
LED_init_time = 0.0
xsampling = 0.0586
ysampling = 0.0586
zsampling = 1.0
auto_range = True
auto_levels = True
level_min = 6016
level_max = 65408
save_h5 = False
refresh_period = 0.05

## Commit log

2025-05-30 image horizontal arm
2025-06-17 add stl files
    [Arabidopsis_rhyzobox.stl, Light_path_barrier_left.stl, Light_path_barrier_right.stl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]
2025-06-17 add 3d-printing documentation
2025-06-30 update 3d printing docs
